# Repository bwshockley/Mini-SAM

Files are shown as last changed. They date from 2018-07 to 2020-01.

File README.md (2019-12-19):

# Mini SAM
Mini SAM is a LEGO® minifigure-sized development board based on either the Microchip SAMD51G 48-Pin 32-Bit ARM® Cortex®-M4F MCU (Mini SAM M4) or the Microchip SAMD21G 48-Pin 32-Bit ARM® Cortex®-M0+ MCU running at 48Mhz.

## Board Features

### I/O
The boards includes a usb-micro interface for programming and power.   Around the edge are 0.050" spaced holes with castellations outside of that and the plan is to have a "breakout" board with standard .100" headers.  There is an optional board design in work that will be 4-layer and have the .100" smt header pads included.

The Mini SAM boards include two LED indicators; a standard "Built-In" LED and an APA102 RGB LED.  There are two built-in buttons as well; a RESET button and a user programmable BUTTON.

### Memory
In order to support CircuitPython, a 2MB Quad-SPI flash memory chip is included.  This provides plenty of space for the CircuitPython program as well as space for user programming.

### Other
The boards include a 600mA 3.3V regulator, more than enough to power this little board and its built-in features.  The micro-USB circuitry includes optional provisioning for case grounding and ESD protection.  Finally, The AREF input and recommended Analog and Digital power separation is present on the board.

## BOM
Please see the BOM for each board

## Bootloader
A UF2 bootloader is available for the M4 board (will be available for the M0 when ready).  This bootloader may be built from source using my UF2 repository or downloaded from the [Minifigboards Software](https://www.minifigboards.com/mini-sam-m4/software/) page.

Source: [UF2-SAMDX1](https://github.com/bwshockley/uf2-samdx1) 

## Arduino
Arduino firmware is available for the M4 board as well. Instructions for adding the board to the board manager in the Arduino IDE are available on the [Minifigboards Software](https://www.minifigboards.com/mini-sam-m4/software/) page.

## CircuitPython
CircuitPython is available for the M4 board. [Mini SAM M4](https://circuitpython.org/board/mini_sam_m4/)  
CircuitPython will soon be available for the M0 board.

## Open Source
Boards can be ordered direct from [OSHPark](https://oshpark.com/profiles/bwshockley).

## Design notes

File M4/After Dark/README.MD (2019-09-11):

This is the repository for the "After Dark" version of the Mini SAM M4 board.  This design was talored for the "After Dark" option at oshpark.com, but should work for other PCB manufacturing that involves a clear solder mask.

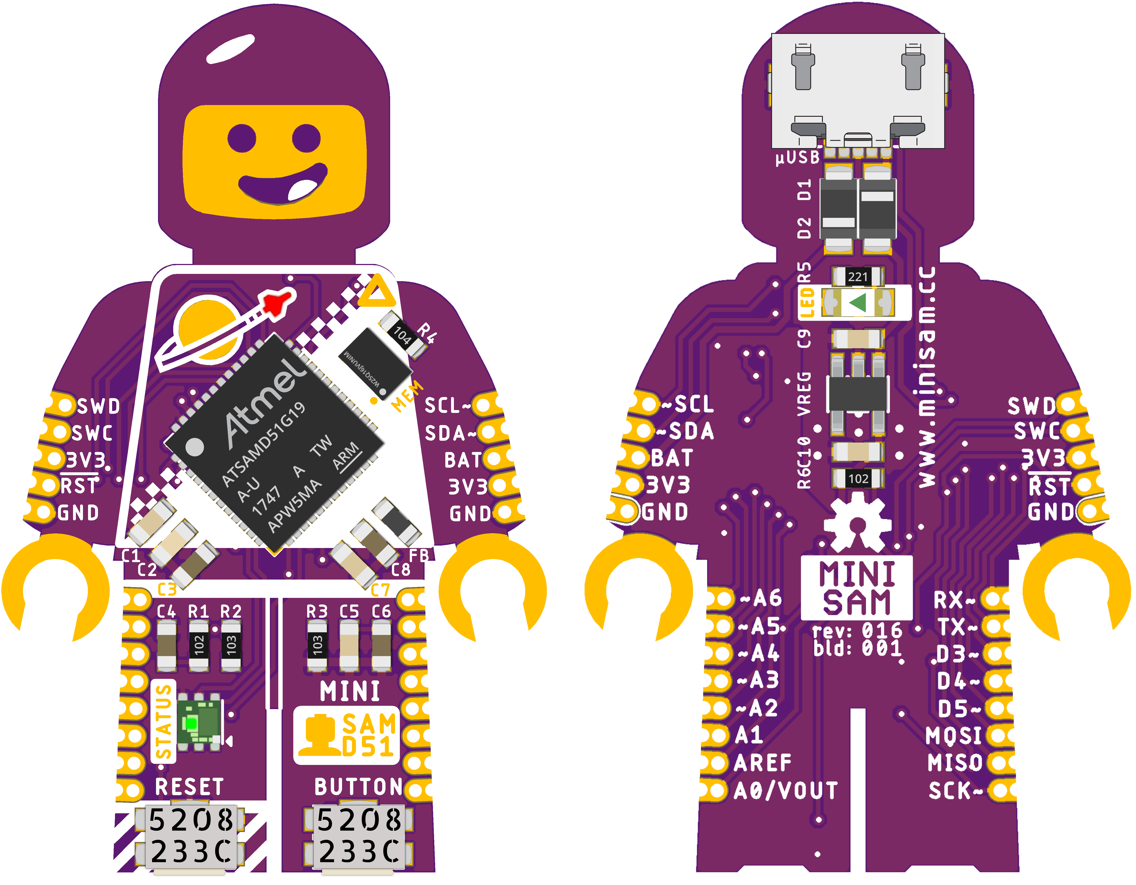
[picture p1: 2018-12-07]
docs/Complete.png

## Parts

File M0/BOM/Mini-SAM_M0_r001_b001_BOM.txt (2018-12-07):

Qty Value                                                            Device                Package                       Parts           Description                                 PROD_ID    VALUE
4   0.1µF                                                            CAP_CERAMIC_0603MP    _0603MP                       C3, C4, C6, C8  Ceramic Capacitors                                          
1   100kO                                                            RESISTOR_0603MP       _0603MP                       R4              Resistors                                                   
2   10KO                                                             RESISTOR_0603MP       _0603MP                       R2, R3          Resistors                                                   
4   10µF                                                             CAP_CERAMIC_0603MP    _0603MP                       C2, C7, C9, C10 Ceramic Capacitors                                          
2   1KO                                                              RESISTOR_0603MP       _0603MP                       R1, R6          Resistors                                                   
2   1X5_HEADER_1.27MMCAST                                            1X5_HEADER_1.27MMCAST 1X5_HEADER_1.27MM_CASTELLATED J2, J4                                                                      
2   1X8_HEADER_1.27MMCAST                                            1X8_HEADER_1.27MMCAST 1X8_HEADER_1.27MM_CASTELLATED J3, J5                                                                      
1   220O                                                             RESISTOR_0603MP       _0603MP                       R5              Resistors                                                   
2   4.7µF                                                            CAP_CERAMIC_0603MP    _0603MP                       C1, C5          Ceramic Capacitors                                          
1   AP102-2020                                                       APA1022020            APA102_2020                   RGB             APA102/DotStar Pixels                                       
1   AP2112K-3.3V                                                     V_REG_AP2112K-3.3V    SOT23-5                       VREG            AP2112 - 600mA CMOS LDO Regulator w/ Enable VREG-12457 3.3V 
1   ATSAMD21G18                                                      ATSAMD21G_QFN         TQFN48_7MM                    U1                                                                          
1   Easily mounted up-sdie down.                                     LED0805_NOOUTLINE     CHIPLED_0805_NOOUTLINE        LED             LED                                                         
1   Impedence: 50 ohm @ 20 MHz, 220 Ohm @ 100 MHz; low DC resistance FERRITE_0603MP        _0603MP                       FB              Ferrite Bead                                                
2   KMS233GLFG                                                       KMS_SWITCHKMS         KMS_SWITCH                    SW1, SW2                                                                    
2   MBR120                                                           DIODE_SOD-123FL       SOD-123FL                     D1, D2          Diode                                                       
1   MOLEX_47346-100147346                                            MOLEX_47346-100147346 MOLEX_47346-1001              J1                                                                          
1   flash                                                            SPIFLASH_8PINUX       USON8                         U3              SOIC8 SPI Flash

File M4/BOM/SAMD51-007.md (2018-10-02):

**Check the capacitors!  I've made a mistake and this BOM is wrong.  Will update when I can.**

Partlist exported from C:/Users/shockleyb/CloudStation/Eagle/Circuits/MiniSAMD51/Mini-SAM-D51/MINI_SAM_D51_007.sch at 7/31/2018 3:42 PM

Qty Value                 Device                Package                Parts               Description                                 
Others
1                         FERRITE BEAD*         0603                   FB                  Ferrite Bead
1                         LED                   0603                   L                   LED                                         
                            
Capacitors
5   0.1µF                 CAP_CERAMIC           0603                   C1, C3, C7, C8, C12 Ceramic Capacitors
4   10µF                  CAP_CERAMIC           0603                   C2, C9, C10, C11    Ceramic Capacitors
1   4.7nF                 CAP_CERAMIC           0603                   C13                 Ceramic Capacitors                          
1   4.7µF                 CAP_CERAMIC           0603                   C6                  Ceramic Capacitors

Resistors
1   100k                  RESISTOR              0603                   R7                  Resistors                                   
2   10K                   RESISTOR              0603                   R4, R5              Resistors                                   
1   1M                    RESISTOR              0603                   R6                  Resistors                                   
2   1k                    RESISTOR              0603                   R2**, R8            Resistors                                   
1   330Ohm                RESISTOR              0603                   R3                  Resistors                                   

ICs
1   AP102-2020            APA1022020            APA102_2020            RGB                 APA102/DotStar Pixels                       
1   AP2112K-3.3V          AP2112K-3.3V          SOT23-5                VREG                AP2112 - 600mA CMOS LDO Regulator w/ Enable 
1   ATSAMD51G_TQFN48      ATSAMD51G_TQFN48      TQFN48_7MM             IC4                 Main CPU    
1   2MB FLASH             IS25LP016D-JULE       USON8 (2x3mm)          U1                  USON8 2mmx3mm QSPI Flash
1   PRTR5V0U2X            PRTR5V0U2X            SOT143B                IC2                 ESD Protection for USB.

Connectors/Switches
2   KMS233GLFG            KMS_SWITCHKMS         KMS_SWITCH             SW1, SW2                                                        
1   MOLEX_47346-100147346 MOLEX_47346-100147346 MOLEX_47346-1001       J1                  Micro-USB Connector

Headers
1                         CORTEX_DEBUG_PTH      2X5-PTH-1.27MM         J2                  Cortex Debug Connector - 10 pin
2                         PINHD-1X111X11_SMT    1X11_SMT               J3, J4              PIN HEADER, SMT   

*The bead should provide enough impedance (e.g., 50Ω at 20 MHz and 220Ω at 100 MHz) to separate the digital and analog power domains.
Make sure to select a ferrite bead designed for filtering applications with a low DC resistance to avoid a large voltage drop across
the ferrite bead.

**R2 is the LED (L) resistor and when choosing your 0603 sized LED, please choose a resistor to match based on 3.3V supply voltage,
LED voltage drop and desired current.

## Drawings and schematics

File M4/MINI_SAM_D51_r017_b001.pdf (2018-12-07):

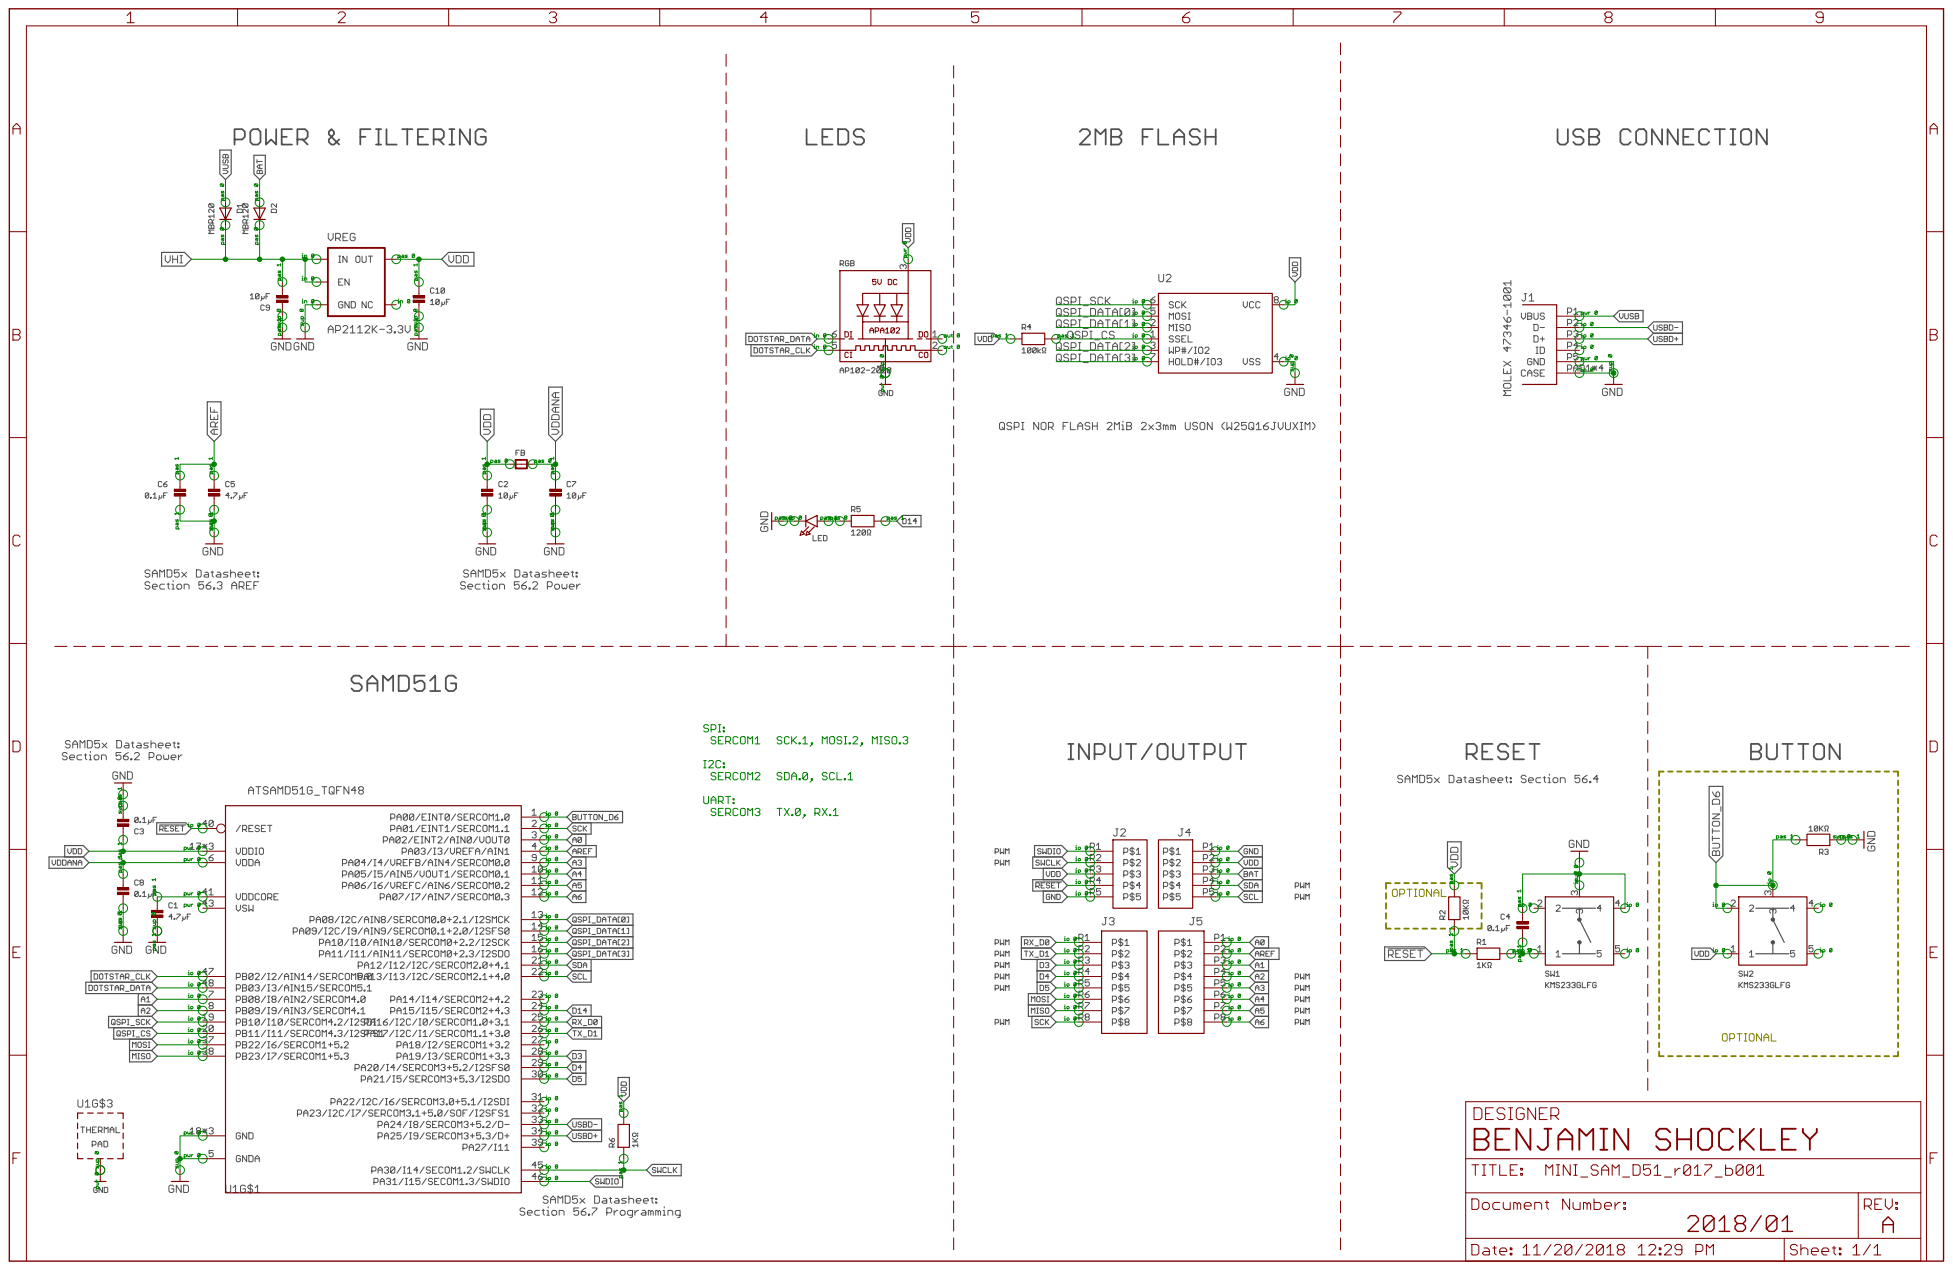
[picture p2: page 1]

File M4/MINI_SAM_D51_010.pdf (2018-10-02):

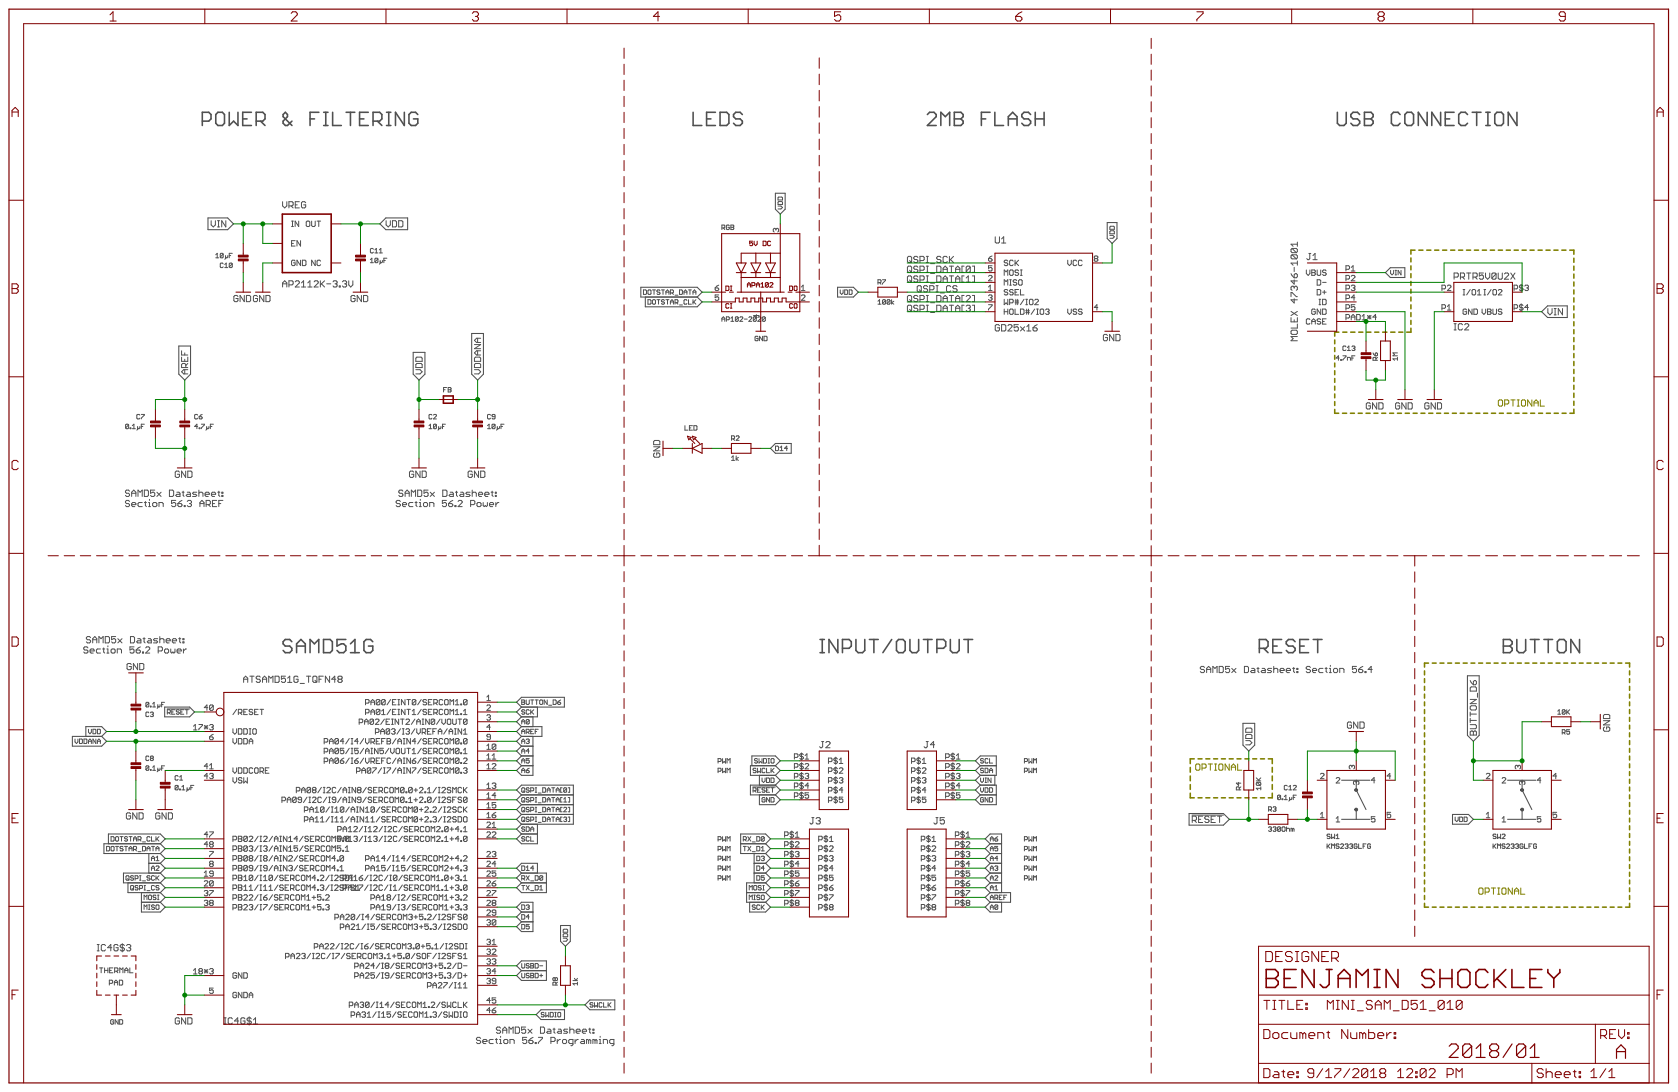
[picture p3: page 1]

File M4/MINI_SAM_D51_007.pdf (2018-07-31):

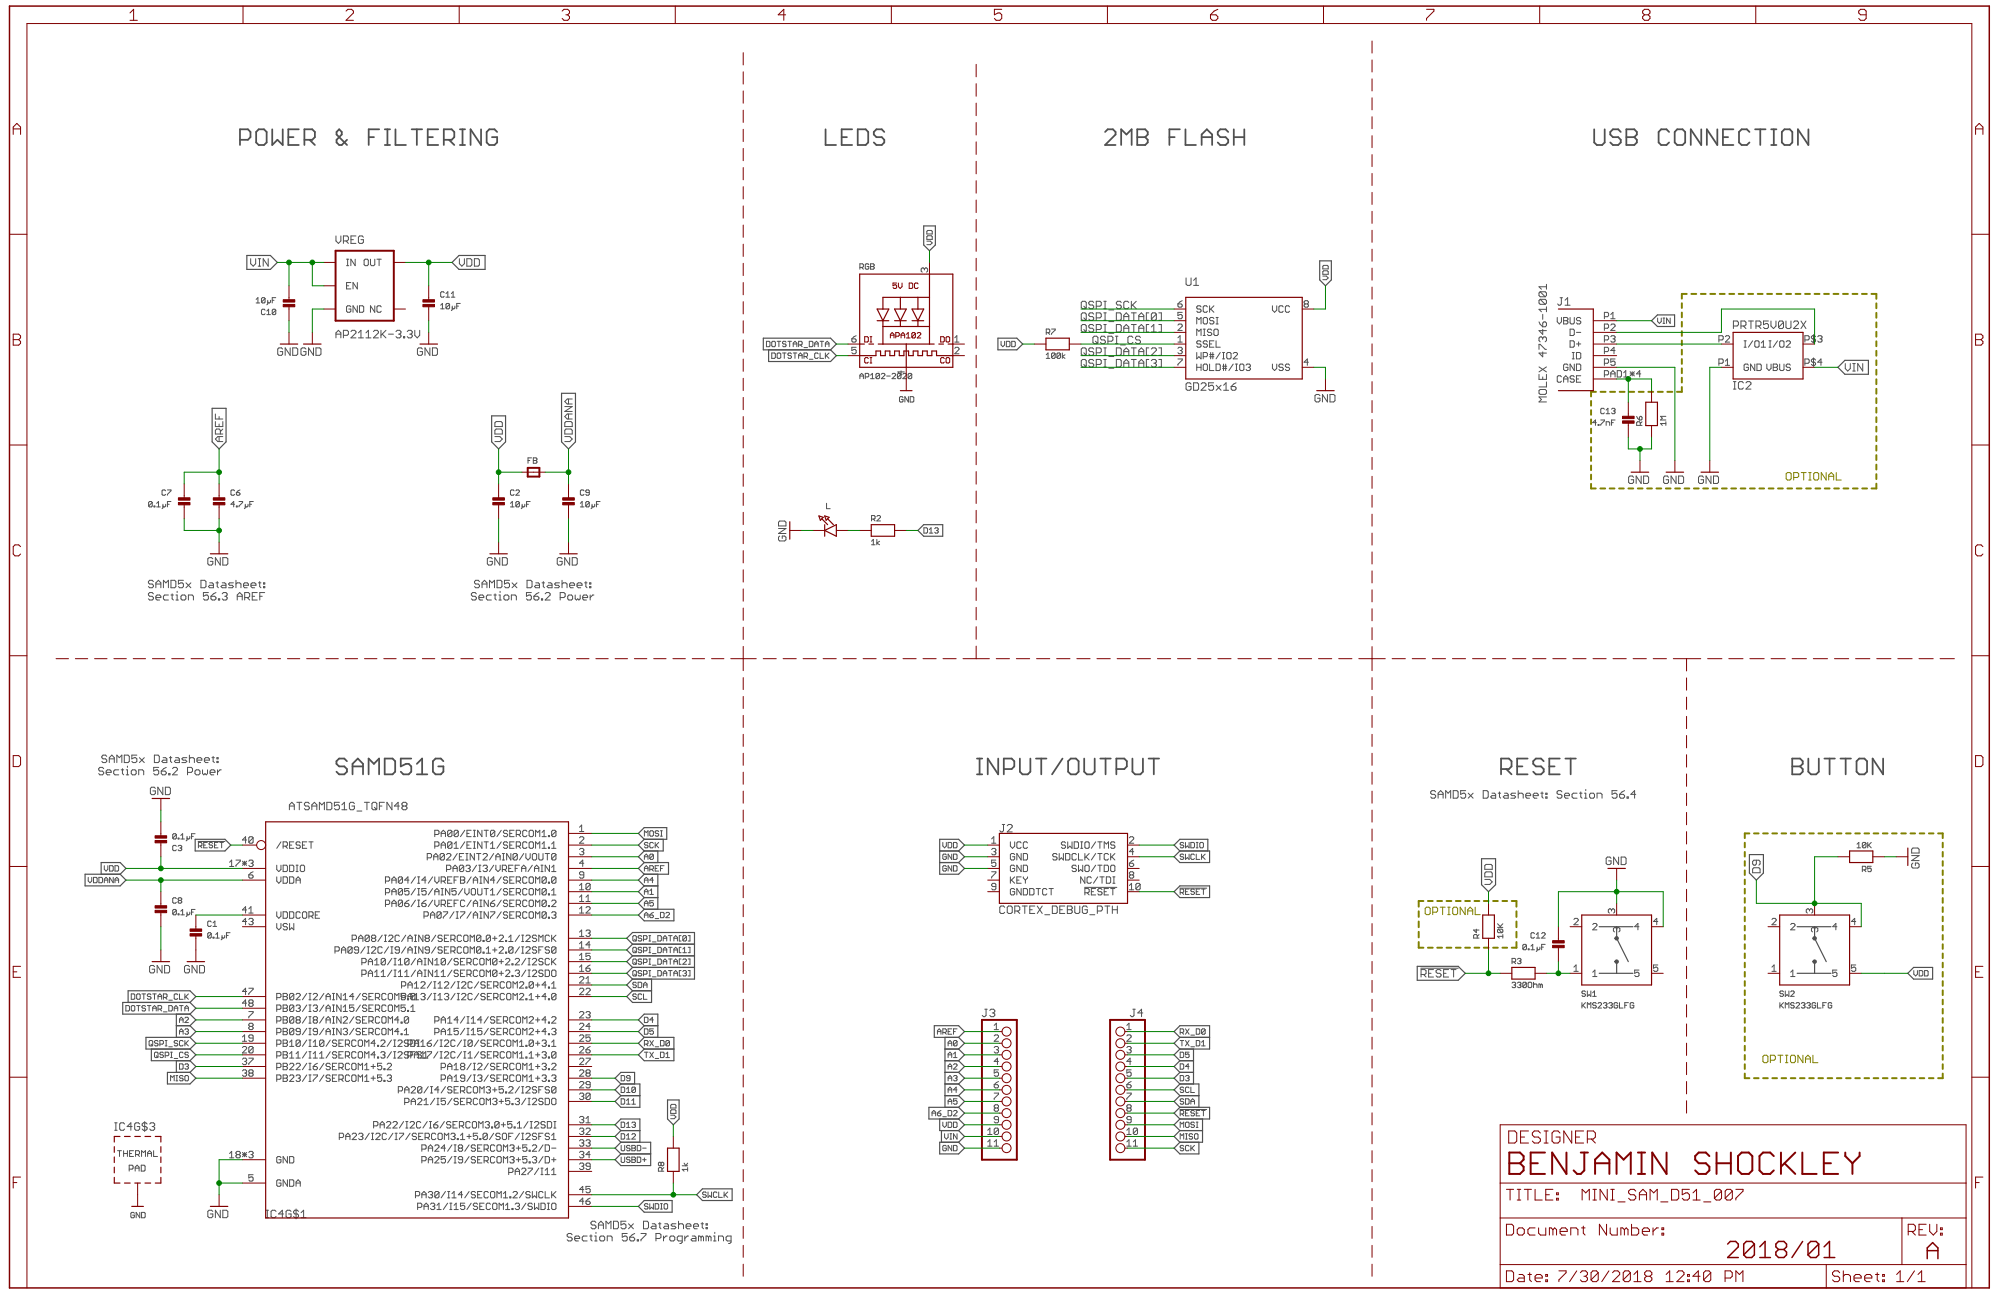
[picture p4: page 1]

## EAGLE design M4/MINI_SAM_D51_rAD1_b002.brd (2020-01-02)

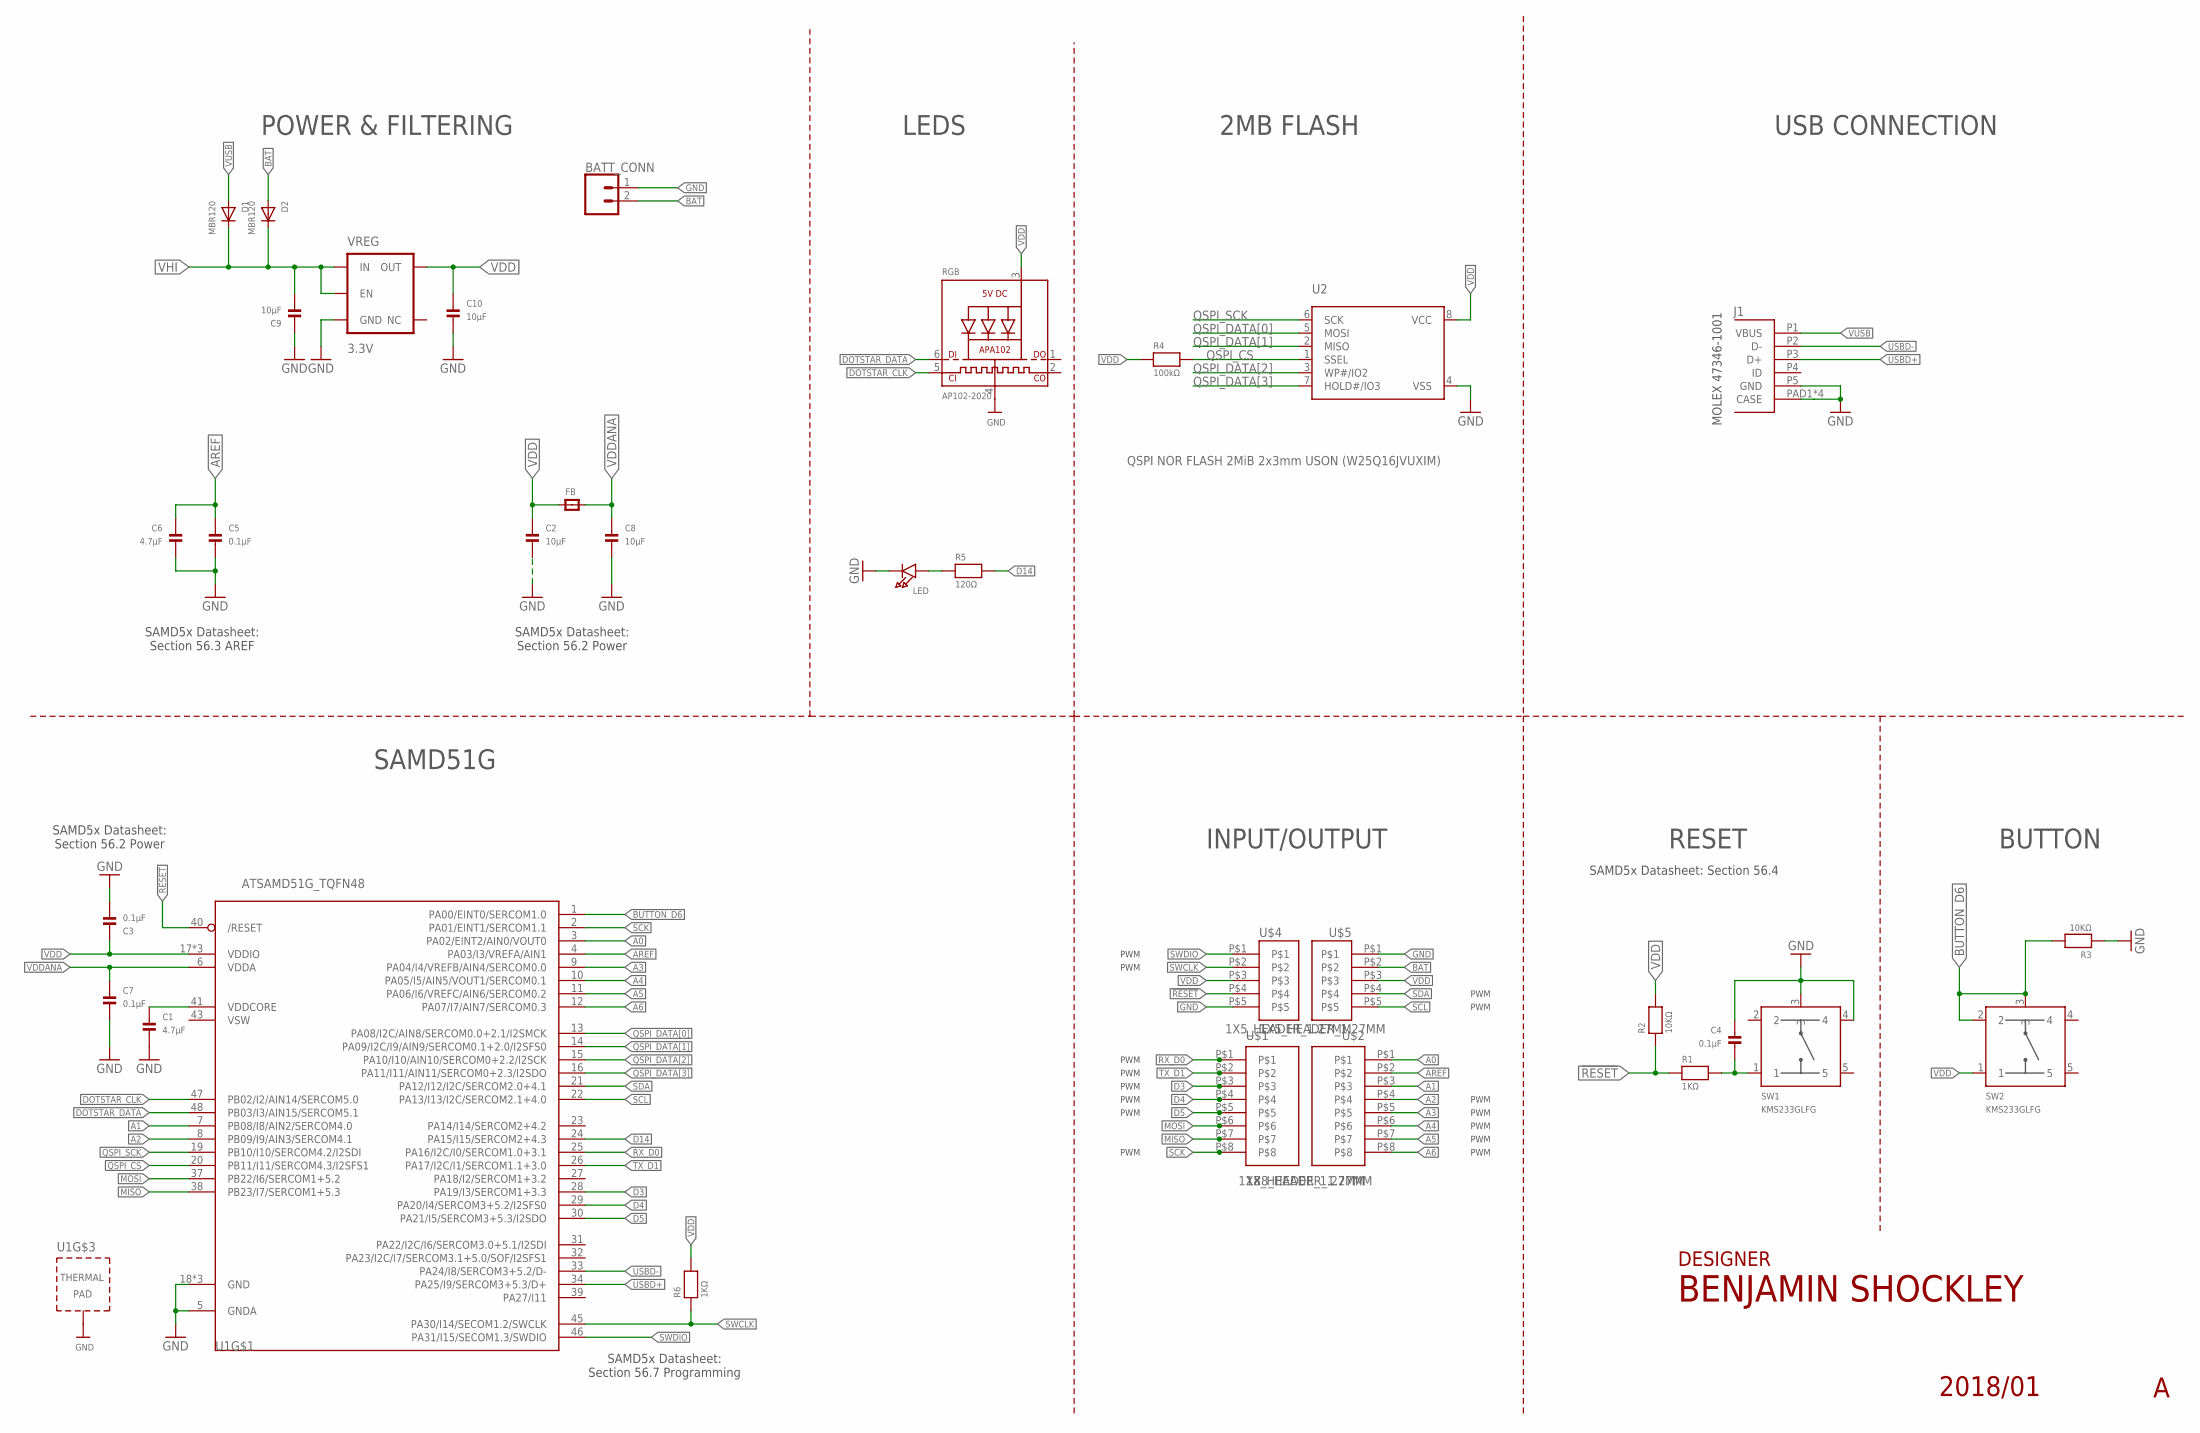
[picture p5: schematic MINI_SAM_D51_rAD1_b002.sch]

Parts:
BATT_CONN: CONN_02-JST-2MM-SMT; JST-2-SMD_NO_PASTE
C1, C6: 4.7µF; 0603_CAPACITOR
C2, C8, C9, C10: 10µF; 0603_CAPACITOR
C3, C4, C5, C7: 0.1µF; 0603_CAPACITOR
D1, D2: MBR120; SOD-123FL
FB: Impedence: 50 ohm @ 20 MHz, 220 Ohm @ 100 MHz; lo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; 0603_INDUCTOR
J1: MOLEX_47346-100147346; MOLEX_47346-1001
LED: VLRK31Q1R2-GS08; REVERSE_MOUNT_LED
R1, R6: 1KΩ; 0603_RESISTOR
R2, R3: 10KΩ; 0603_RESISTOR
R4: 100kΩ; 0603_RESISTOR
R5: 120Ω; 0603_RESISTOR
RGB: AP102-2020; APA102_2020
SW1, SW2: KMS233GLFG; KMS_SWITCH
U1: ATSAMD51G_TQFN48; TQFN48_7MM
U2: QSPI NOR FLASH 2MiB 2x3mm USON (W25Q16JVUXIM); USON8
U$1, U$2: 1X8_HEADER_1.27MM
U$4, U$5: 1X5_HEADER_1.27MM
VREG: 3.3V; SOT23-5

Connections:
!RESET: R1.1, R2.1, U1.40 (/RESET), U$4.P$4
A0: U1.3 (PA02/EINT2/AIN0/VOUT0), U$2.P$1
A1: U1.7 (PB08/I8/AIN2/SERCOM4.0), U$2.P$3
A2: U1.8 (PB09/I9/AIN3/SERCOM4.1), U$2.P$4
A3: U1.9 (PA04/I4/VREFB/AIN4/SERCOM0.0), U$2.P$5
A4: U1.10 (PA05/I5/AIN5/VOUT1/SERCOM0.1), U$2.P$6
A5: U1.11 (PA06/I6/VREFC/AIN6/SERCOM0.2), U$2.P$7
A6: U1.12 (PA07/I7/AIN7/SERCOM0.3), U$2.P$8
AREF: C5.1, C6.1, U1.4 (PA03/I3/VREFA/AIN1), U$2.P$2
BAT: BATT_CONN.2 (1), D2.A, U$5.P$2
BUTTON_D6: R3.2, SW2.2, SW2.3, U1.1 (PA00/EINT0/SERCOM1.0)
D3: U1.28 (PA19/I3/SERCOM1+3.3), U$1.P$3
D4: U1.29 (PA20/I4/SERCOM3+5.2/I2SFS0), U$1.P$4
D5: U1.30 (PA21/I5/SERCOM3+5.3/I2SDO), U$1.P$5
D14: R5.2, U1.24 (PA15/I15/SERCOM2+4.3)
DOTSTAR_CLK: RGB.5 (CKI), U1.47 (PB02/I2/AIN14/SERCOM5.0)
DOTSTAR_DATA: RGB.6 (DI), U1.48 (PB03/I3/AIN15/SERCOM5.1)
GND: BATT_CONN.1 (2), C1.2, C2.2, C3.2, C4.1, C5.2, C6.2, C7.2, C8.2, C9.1, C10.2, J1.P5 (GND), J1.PAD1 (CASE), J1.PAD2 (CASE), J1.PAD3 (CASE), J1.PAD4 (CASE), LED.C, R3.1, RGB.4 (GND), SW1.3, SW1.4, U1.5 (GNDA), U1.18 (GND), U1.35 (GND), U1.42 (GND), U1.THERMAL (TP), U2.4 (VSS), U$4.P$5, U$5.P$1, VREG.2 (GND)
MISO: U1.38 (PB23/I7/SERCOM1+5.3), U$1.P$7
MOSI: U1.37 (PB22/I6/SERCOM1+5.2), U$1.P$6
unnamed: LED.A, R5.1
unnamed: C4.2, R1.2, SW1.1
unnamed: C1.1, U1.41 (VDDCORE)
QSPI_CS: R4.2, U1.20 (PB11/I11/SERCOM4.3/I2SFS1), U2.1 (SSEL)
QSPI_DATA[0]: U1.13 (PA08/I2C/AIN8/SERCOM0.0+2.1/I2SMCK), U2.5 (MOSI)
QSPI_DATA[1]: U1.14 (PA09/I2C/I9/AIN9/SERCOM0.1+2.0/I2SFS0), U2.2 (MISO)
QSPI_DATA[2]: U1.15 (PA10/I10/AIN10/SERCOM0+2.2/I2SCK), U2.3 (WP#/IO2)
QSPI_DATA[3]: U1.16 (PA11/I11/AIN11/SERCOM0+2.3/I2SDO), U2.7 (HOLD#/IO3)
QSPI_SCK: U1.19 (PB10/I10/SERCOM4.2/I2SDI), U2.6 (SCK)
RX_D0: U1.25 (PA16/I2C/I0/SERCOM1.0+3.1), U$1.P$1
SCK: U1.2 (PA01/EINT1/SERCOM1.1), U$1.P$8
SCL: U1.22 (PA13/I13/I2C/SERCOM2.1+4.0), U$5.P$5
SDA: U1.21 (PA12/I12/I2C/SERCOM2.0+4.1), U$5.P$4
SWCLK: R6.1, U1.45 (PA30/I14/SECOM1.2/SWCLK), U$4.P$2
SWDIO: U1.46 (PA31/I15/SECOM1.3/SWDIO), U$4.P$1
TX_D1: U1.26 (PA17/I2C/I1/SERCOM1.1+3.0), U$1.P$2
USBD+: J1.P3 (D+), U1.34 (PA25/I9/SERCOM3+5.3/D+)
USBD-: J1.P2 (D-), U1.33 (PA24/I8/SERCOM3+5.2/D-)
VDD: C2.1, C3.1, C10.1, FB.1, R2.2, R4.1, R6.2, RGB.3 (VDD), SW2.1, U1.17 (VDDIO), U1.36 (VDDIO), U1.44 (VDDIO), U2.8 (VCC), U$4.P$3, U$5.P$3, VREG.5 (OUT)
VDDANA: C7.1, C8.1, FB.2, U1.6 (VDDA)
VHI: C9.2, D1.C, D2.C, VREG.1 (IN), VREG.3 (EN)
VSW: U1.43 (VSW)
VUSB: D1.A, J1.P1 (VBUS)

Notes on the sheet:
INPUT/OUTPUT
RESET
POWER & FILTERING
SAMD51G
LEDS
USB CONNECTION
MOLEX 47346-1001
BUTTON
DESIGNER
SAMD5x Datasheet: Section 56.4
2MB FLASH
SAMD5x Datasheet: Section 56.3 AREF
SAMD5x Datasheet: Section 56.2 Power
SAMD5x Datasheet: Section 56.7 Programming
PWM

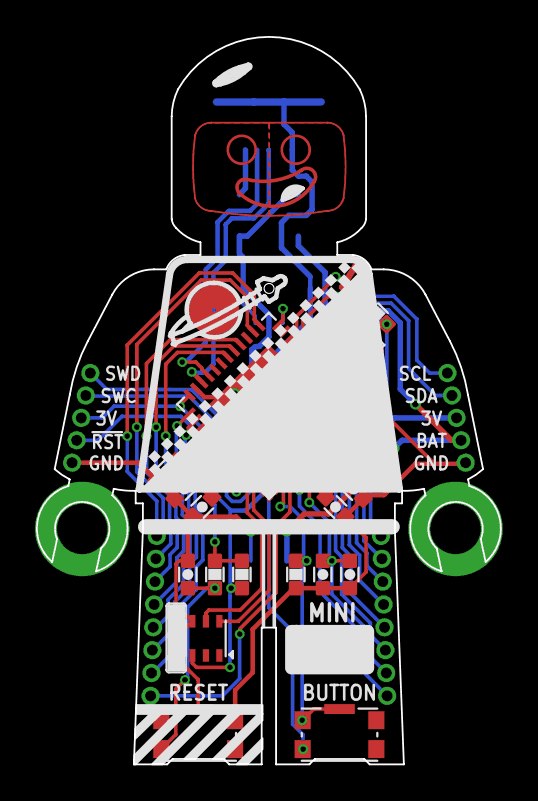
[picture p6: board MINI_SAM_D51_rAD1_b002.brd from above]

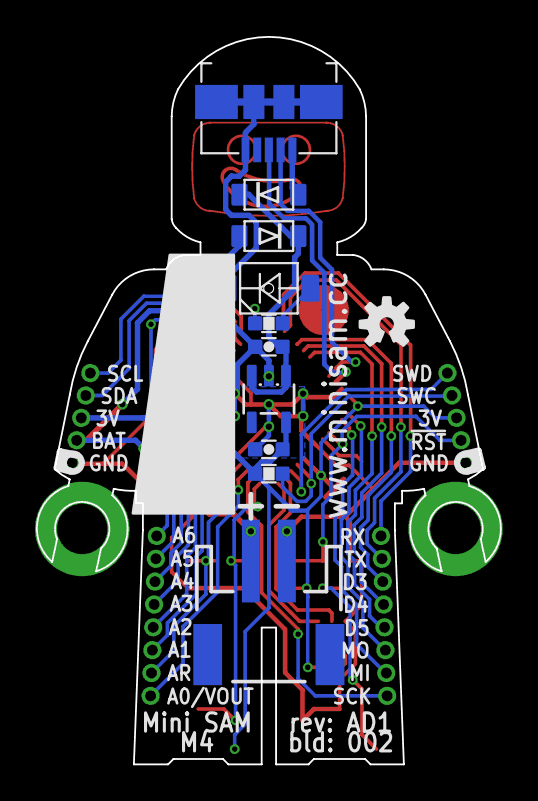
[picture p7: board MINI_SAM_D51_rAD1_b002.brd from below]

Board: 2 copper layers, 25.8 x 40.4 mm, 33 parts (11 on the bottom side), 42 nets.

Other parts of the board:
U$3: OSHW-LOGO-S

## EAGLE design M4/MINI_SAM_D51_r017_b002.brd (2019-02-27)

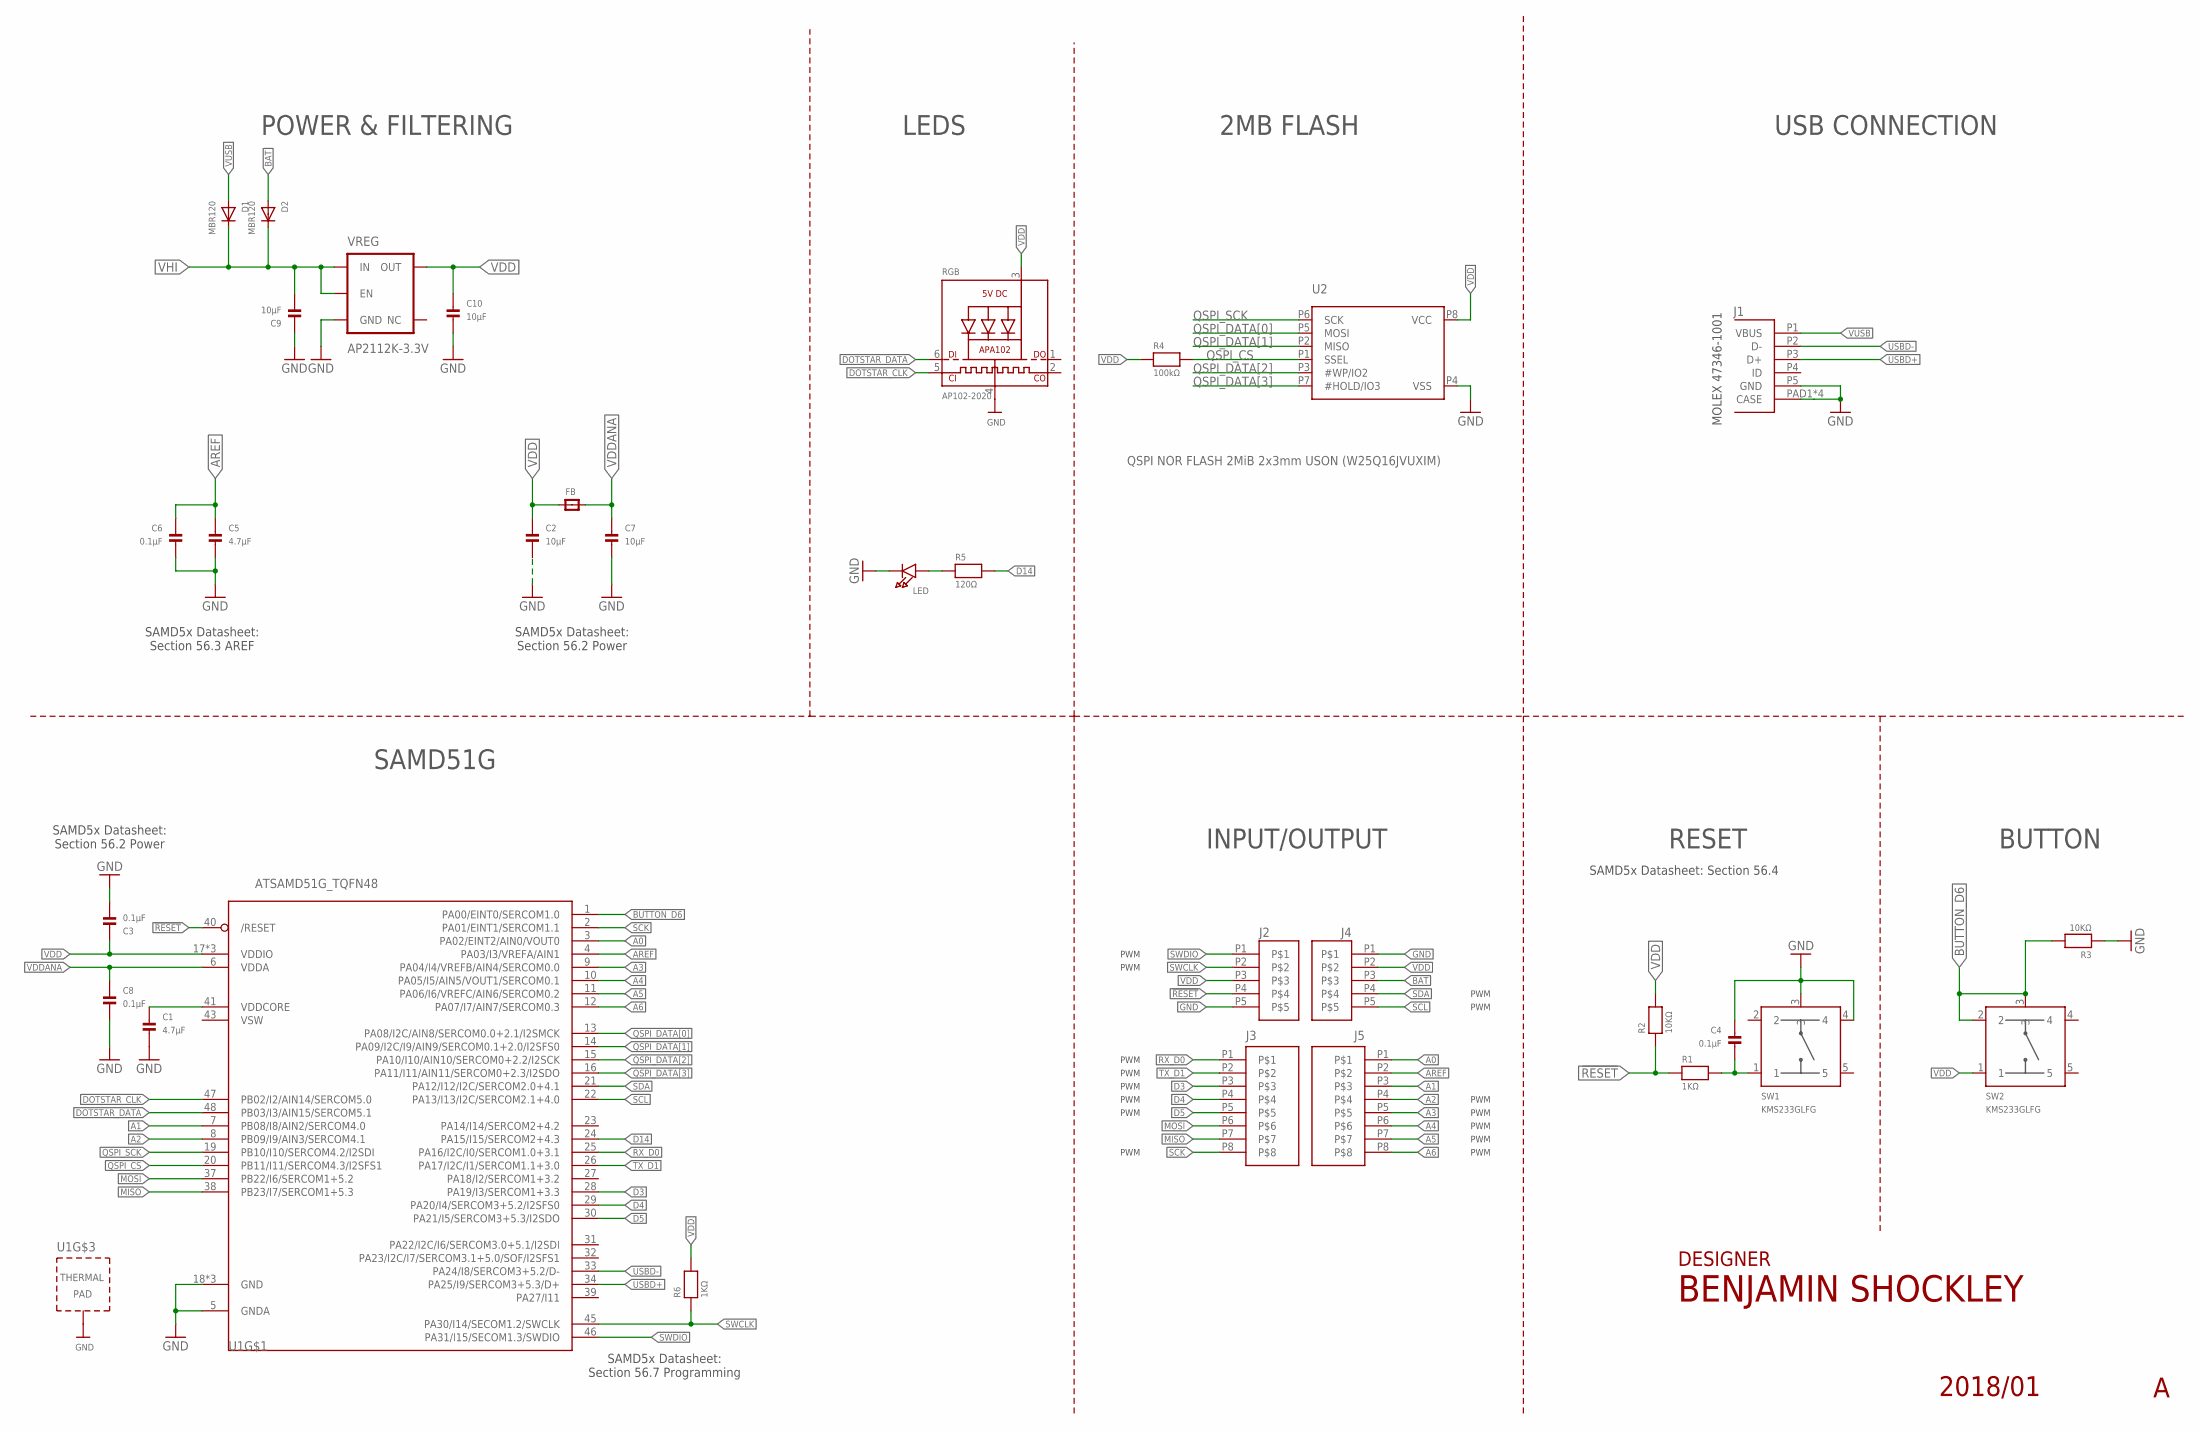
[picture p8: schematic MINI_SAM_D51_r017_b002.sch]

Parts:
C1, C5: 4.7µF; _0603MP
C2, C7, C9, C10: 10µF; _0603MP
C3, C4, C6, C8: 0.1µF; _0603MP
D1, D2: MBR120; SOD-123FL
FB: Impedence: 50 ohm @ 20 MHz, 220 Ohm @ 100 MHz; lo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; _0603MP
J1: MOLEX_47346-100147346; MOLEX_47346-1001
J2, J4: 1X5_HEADER_1.27MMCAST; 1X5_HEADER_1.27MM_CASTELLATED
J3, J5: 1X8_HEADER_1.27MMCAST; 1X8_HEADER_1.27MM_CASTELLATED
LED: VLRK31Q1R2-GS08; REVERSE_MOUNT_LED
R1, R6: 1KΩ; _0603MP
R2, R3: 10KΩ; _0603MP
R4: 100kΩ; _0603MP
R5: 120Ω; _0603MP
RGB: AP102-2020; APA102_2020
SW1, SW2: KMS233GLFG; KMS_SWITCH
U1: ATSAMD51G_TQFN48; TQFN48_7MM
U2: QSPI NOR FLASH 2MiB 2x3mm USON (W25Q16JVUXIM); USON4X3
VREG: AP2112K-3.3V; SOT23-5

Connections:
!RESET: J2.P4, R1.1, R2.1, U1.40 (/RESET)
A0: J5.P1, U1.3 (PA02/EINT2/AIN0/VOUT0)
A1: J5.P3, U1.7 (PB08/I8/AIN2/SERCOM4.0)
A2: J5.P4, U1.8 (PB09/I9/AIN3/SERCOM4.1)
A3: J5.P5, U1.9 (PA04/I4/VREFB/AIN4/SERCOM0.0)
A4: J5.P6, U1.10 (PA05/I5/AIN5/VOUT1/SERCOM0.1)
A5: J5.P7, U1.11 (PA06/I6/VREFC/AIN6/SERCOM0.2)
A6: J5.P8, U1.12 (PA07/I7/AIN7/SERCOM0.3)
AREF: C5.1, C6.1, J5.P2, U1.4 (PA03/I3/VREFA/AIN1)
BAT: D2.A, J4.P3
BUTTON_D6: R3.2, SW2.2, SW2.3, U1.1 (PA00/EINT0/SERCOM1.0)
D3: J3.P3, U1.28 (PA19/I3/SERCOM1+3.3)
D4: J3.P4, U1.29 (PA20/I4/SERCOM3+5.2/I2SFS0)
D5: J3.P5, U1.30 (PA21/I5/SERCOM3+5.3/I2SDO)
D14: R5.2, U1.24 (PA15/I15/SERCOM2+4.3)
DOTSTAR_CLK: RGB.5 (CKI), U1.47 (PB02/I2/AIN14/SERCOM5.0)
DOTSTAR_DATA: RGB.6 (DI), U1.48 (PB03/I3/AIN15/SERCOM5.1)
GND: C1.2, C2.2, C3.2, C4.1, C5.2, C6.2, C7.2, C8.2, C9.1, C10.2, J1.P5 (GND), J1.PAD1 (CASE), J1.PAD2 (CASE), J1.PAD3 (CASE), J1.PAD4 (CASE), J2.P5, J4.P1, LED.C, R3.1, RGB.4 (GND), SW1.3, SW1.4, U1.5 (GNDA), U1.18 (GND), U1.35 (GND), U1.42 (GND), U1.THERMAL (TP), U2.P4 (VSS), VREG.2 (GND)
MISO: J3.P7, U1.38 (PB23/I7/SERCOM1+5.3)
MOSI: J3.P6, U1.37 (PB22/I6/SERCOM1+5.2)
unnamed: LED.A, R5.1
unnamed: C4.2, R1.2, SW1.1
unnamed: C1.1, U1.41 (VDDCORE)
QSPI_CS: R4.2, U1.20 (PB11/I11/SERCOM4.3/I2SFS1), U2.P1 (SSEL)
QSPI_DATA[0]: U1.13 (PA08/I2C/AIN8/SERCOM0.0+2.1/I2SMCK), U2.P5 (MOSI)
QSPI_DATA[1]: U1.14 (PA09/I2C/I9/AIN9/SERCOM0.1+2.0/I2SFS0), U2.P2 (MISO)
QSPI_DATA[2]: U1.15 (PA10/I10/AIN10/SERCOM0+2.2/I2SCK), U2.P3 (#WP/IO2)
QSPI_DATA[3]: U1.16 (PA11/I11/AIN11/SERCOM0+2.3/I2SDO), U2.P7 (#HOLD/IO3)
QSPI_SCK: U1.19 (PB10/I10/SERCOM4.2/I2SDI), U2.P6 (SCK)
RX_D0: J3.P1, U1.25 (PA16/I2C/I0/SERCOM1.0+3.1)
SCK: J3.P8, U1.2 (PA01/EINT1/SERCOM1.1)
SCL: J4.P5, U1.22 (PA13/I13/I2C/SERCOM2.1+4.0)
SDA: J4.P4, U1.21 (PA12/I12/I2C/SERCOM2.0+4.1)
SWCLK: J2.P2, R6.1, U1.45 (PA30/I14/SECOM1.2/SWCLK)
SWDIO: J2.P1, U1.46 (PA31/I15/SECOM1.3/SWDIO)
TX_D1: J3.P2, U1.26 (PA17/I2C/I1/SERCOM1.1+3.0)
USBD+: J1.P3 (D+), U1.34 (PA25/I9/SERCOM3+5.3/D+)
USBD-: J1.P2 (D-), U1.33 (PA24/I8/SERCOM3+5.2/D-)
VDD: C2.1, C3.1, C10.1, FB.1, J2.P3, J4.P2, R2.2, R4.1, R6.2, RGB.3 (VDD), SW2.1, U1.17 (VDDIO), U1.36 (VDDIO), U1.44 (VDDIO), U2.P8 (VCC), VREG.5 (OUT)
VDDANA: C7.1, C8.1, FB.2, U1.6 (VDDA)
VHI: C9.2, D1.C, D2.C, VREG.1 (IN), VREG.3 (EN)
VSW: U1.43 (VSW)
VUSB: D1.A, J1.P1 (VBUS)

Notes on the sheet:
INPUT/OUTPUT
RESET
POWER & FILTERING
SAMD51G
LEDS
USB CONNECTION
MOLEX 47346-1001
BUTTON
DESIGNER
SAMD5x Datasheet: Section 56.4
2MB FLASH
SAMD5x Datasheet: Section 56.3 AREF
SAMD5x Datasheet: Section 56.2 Power
SAMD5x Datasheet: Section 56.7 Programming
PWM

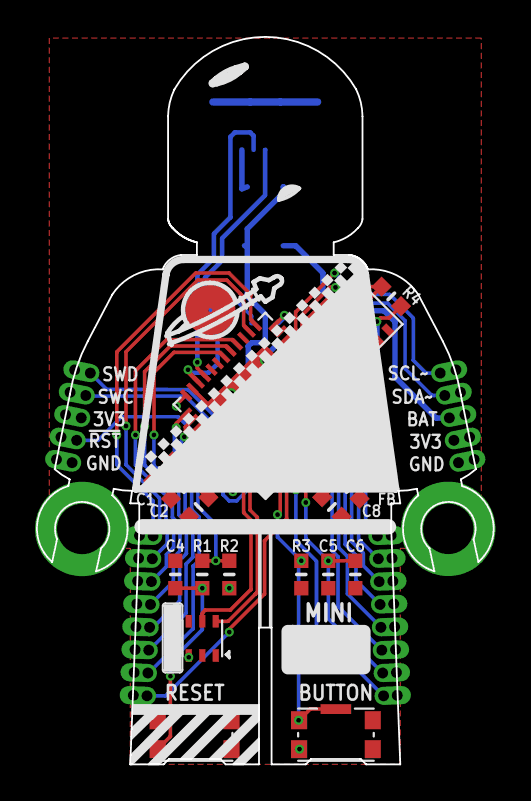
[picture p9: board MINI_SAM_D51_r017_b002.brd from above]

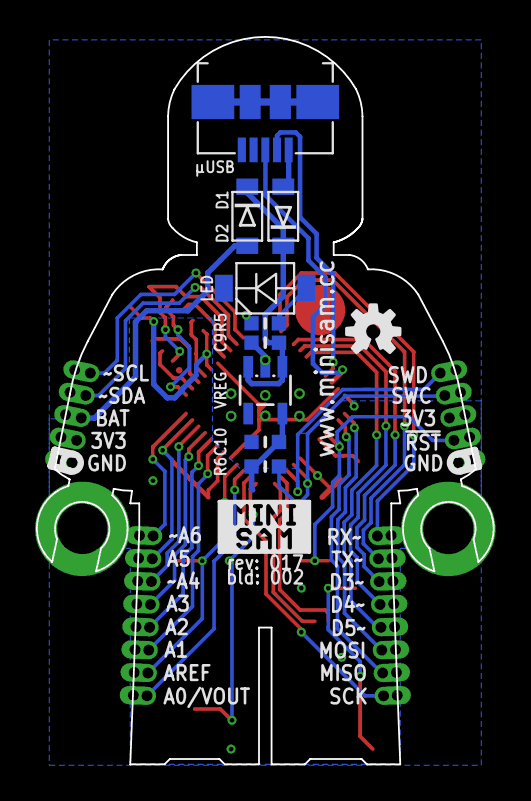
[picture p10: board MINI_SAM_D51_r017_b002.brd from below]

Board: 2 copper layers, 25.4 x 40.4 mm, 32 parts (10 on the bottom side), 42 nets.

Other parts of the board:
U$3: OSHW-LOGO-S

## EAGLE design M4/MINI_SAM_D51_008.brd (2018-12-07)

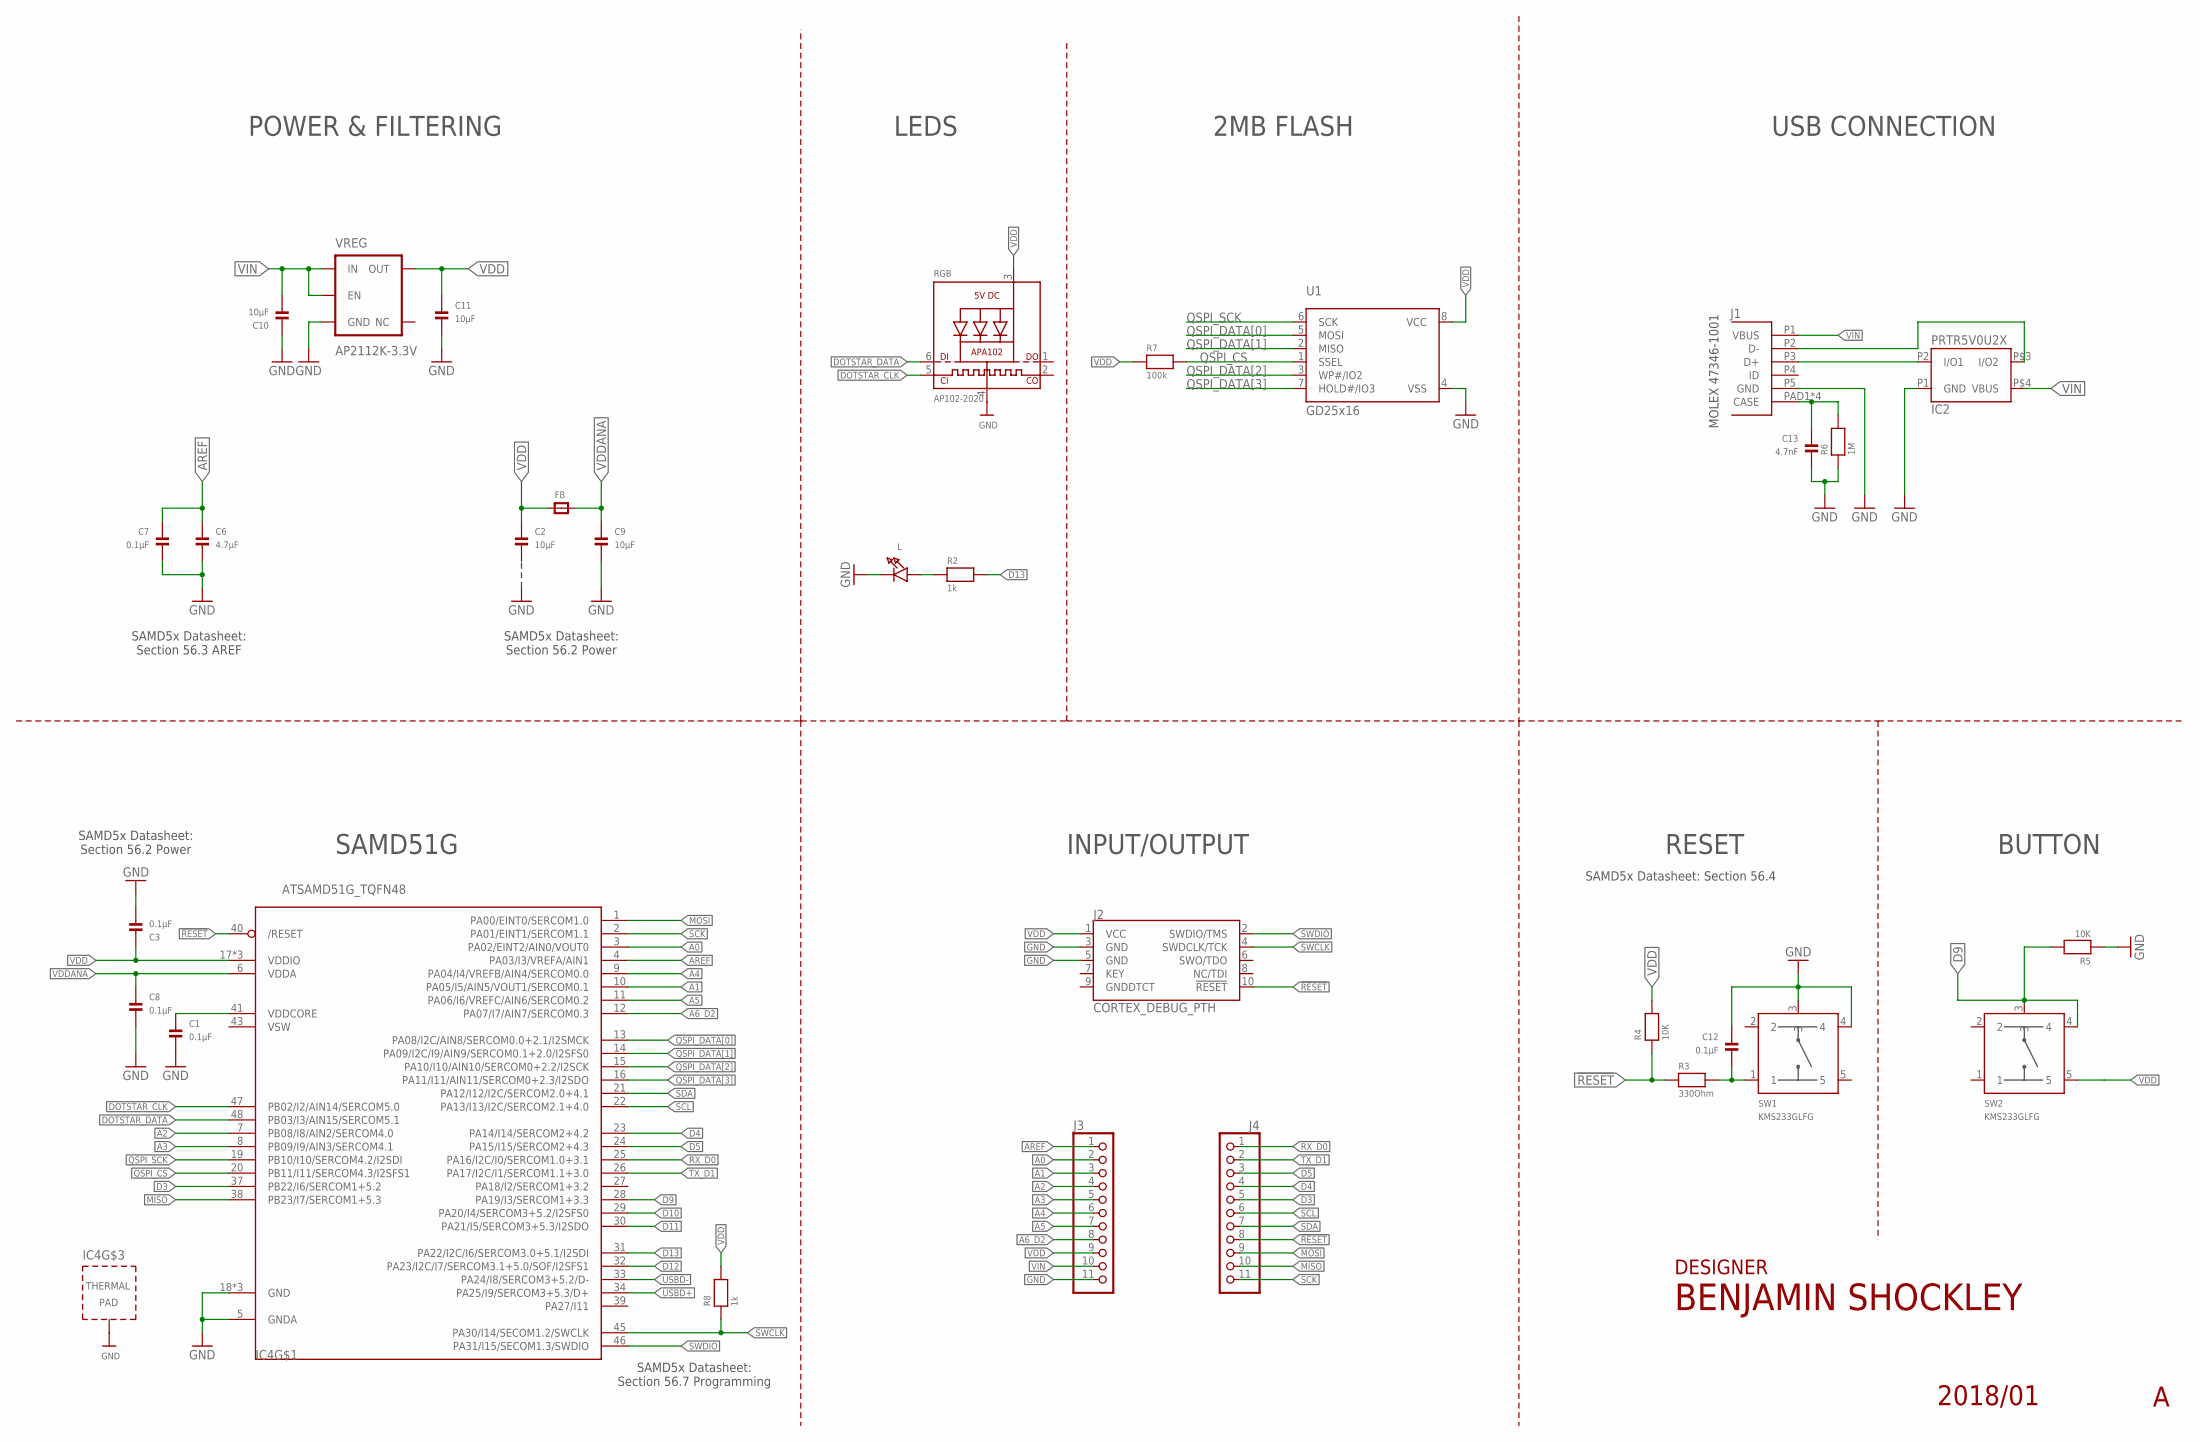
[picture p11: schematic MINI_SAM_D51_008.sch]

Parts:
C1, C3, C7, C8, C12: 0.1µF; _0603MP
C2, C9, C10, C11: 10µF; _0603MP
C6: 4.7µF; _0603MP
C13: 4.7nF; _0603MP
FB: FERRITE_0603MP; _0603MP
IC2: PRTR5V0U2X; SOT143B_REFLOW
IC4: ATSAMD51G_TQFN48; TQFN48_7MM
J1: MOLEX_47346-100147346; MOLEX_47346-1001
J2: CORTEX_DEBUG_PTH; 2X5-PTH-1.27MM
J3, J4: PINHD-1X111X11_SMT; 1X11_SMT
L: LED0603_NOOUTLINE; CHIPLED_0603_NOOUTLINE
R2, R8: 1k; _0603MP
R3: 330Ohm; _0603MP
R4, R5: 10K; _0603MP
R6: 1M; _0603MP
R7: 100k; _0603MP
RGB: AP102-2020; APA102_2020
SW1, SW2: KMS233GLFG; KMS_SWITCH
U1: GD25x16; USON8
VREG: AP2112K-3.3V; SOT23-5

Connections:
!RESET: IC4.40 (/RESET), J2.10 (!RESET), J4.8, R3.1, R4.1
A0: IC4.3 (PA02/EINT2/AIN0/VOUT0), J3.2
A1: IC4.10 (PA05/I5/AIN5/VOUT1/SERCOM0.1), J3.3
A2: IC4.7 (PB08/I8/AIN2/SERCOM4.0), J3.4
A3: IC4.8 (PB09/I9/AIN3/SERCOM4.1), J3.5
A4: IC4.9 (PA04/I4/VREFB/AIN4/SERCOM0.0), J3.6
A5: IC4.11 (PA06/I6/VREFC/AIN6/SERCOM0.2), J3.7
A6_D2: IC4.12 (PA07/I7/AIN7/SERCOM0.3), J3.8
AREF: C6.1, C7.1, IC4.4 (PA03/I3/VREFA/AIN1), J3.1
D3: IC4.37 (PB22/I6/SERCOM1+5.2), J4.5
D4: IC4.23 (PA14/I14/SERCOM2+4.2), J4.4
D5: IC4.24 (PA15/I15/SERCOM2+4.3), J4.3
D9: IC4.28 (PA19/I3/SERCOM1+3.3), R5.2, SW2.3, SW2.4
D10: IC4.29 (PA20/I4/SERCOM3+5.2/I2SFS0)
D11: IC4.30 (PA21/I5/SERCOM3+5.3/I2SDO)
D12: IC4.32 (PA23/I2C/I7/SERCOM3.1+5.0/SOF/I2SFS1)
D13: IC4.31 (PA22/I2C/I6/SERCOM3.0+5.1/I2SDI), R2.2
DOTSTAR_CLK: IC4.47 (PB02/I2/AIN14/SERCOM5.0), RGB.5 (CKI)
DOTSTAR_DATA: IC4.48 (PB03/I3/AIN15/SERCOM5.1), RGB.6 (DI)
GND: C1.2, C2.2, C3.2, C6.2, C7.2, C8.2, C9.2, C10.1, C11.2, C12.1, C13.2, IC2.P1 (GND), IC4.5 (GNDA), IC4.18 (GND), IC4.35 (GND), IC4.42 (GND), IC4.THERMAL (TP), J1.P5 (GND), J2.3 (GND), J2.5 (GND), J3.11, L.C, R5.1, R6.1, RGB.4 (GND), SW1.3, SW1.4, U1.4 (VSS), VREG.2 (GND)
MISO: IC4.38 (PB23/I7/SERCOM1+5.3), J4.10
MOSI: IC4.1 (PA00/EINT0/SERCOM1.0), J4.9
unnamed: C13.1, J1.PAD1 (CASE), J1.PAD2 (CASE), J1.PAD3 (CASE), J1.PAD4 (CASE), R6.2
unnamed: L.A, R2.1
unnamed: C12.2, R3.2, SW1.1
unnamed: C1.1, IC4.41 (VDDCORE)
QSPI_CS: IC4.20 (PB11/I11/SERCOM4.3/I2SFS1), R7.2, U1.1 (SSEL)
QSPI_DATA[0]: IC4.13 (PA08/I2C/AIN8/SERCOM0.0+2.1/I2SMCK), U1.5 (MOSI)
QSPI_DATA[1]: IC4.14 (PA09/I2C/I9/AIN9/SERCOM0.1+2.0/I2SFS0), U1.2 (MISO)
QSPI_DATA[2]: IC4.15 (PA10/I10/AIN10/SERCOM0+2.2/I2SCK), U1.3 (WP#/IO2)
QSPI_DATA[3]: IC4.16 (PA11/I11/AIN11/SERCOM0+2.3/I2SDO), U1.7 (HOLD#/IO3)
QSPI_SCK: IC4.19 (PB10/I10/SERCOM4.2/I2SDI), U1.6 (SCK)
RX_D0: IC4.25 (PA16/I2C/I0/SERCOM1.0+3.1), J4.1
SCK: IC4.2 (PA01/EINT1/SERCOM1.1), J4.11
SCL: IC4.22 (PA13/I13/I2C/SERCOM2.1+4.0), J4.6
SDA: IC4.21 (PA12/I12/I2C/SERCOM2.0+4.1), J4.7
SWCLK: IC4.45 (PA30/I14/SECOM1.2/SWCLK), J2.4 (SWDCLK/TCK), R8.1
SWDIO: IC4.46 (PA31/I15/SECOM1.3/SWDIO), J2.2 (SWDIO/TMS)
TX_D1: IC4.26 (PA17/I2C/I1/SERCOM1.1+3.0), J4.2
USBD+: IC2.P2 (I/O1), IC4.34 (PA25/I9/SERCOM3+5.3/D+), J1.P3 (D+)
USBD-: IC2.P$3 (I/O2), IC4.33 (PA24/I8/SERCOM3+5.2/D-), J1.P2 (D-)
VDD: C2.1, C3.1, C11.1, FB.1, IC4.17 (VDDIO), IC4.36 (VDDIO), IC4.44 (VDDIO), J2.1 (VCC), J3.9, R4.2, R7.1, R8.2, RGB.3 (VDD), SW2.5, U1.8 (VCC), VREG.5 (OUT)
VDDANA: C8.1, C9.1, FB.2, IC4.6 (VDDA)
VIN: C10.2, IC2.P$4 (VBUS), J1.P1 (VBUS), J3.10, VREG.1 (IN), VREG.3 (EN)
VSW: IC4.43 (VSW)

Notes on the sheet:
INPUT/OUTPUT
RESET
POWER & FILTERING
SAMD51G
LEDS
USB CONNECTION
MOLEX 47346-1001
BUTTON
DESIGNER
SAMD5x Datasheet: Section 56.4
2MB FLASH
SAMD5x Datasheet: Section 56.3 AREF
SAMD5x Datasheet: Section 56.2 Power
SAMD5x Datasheet: Section 56.7 Programming

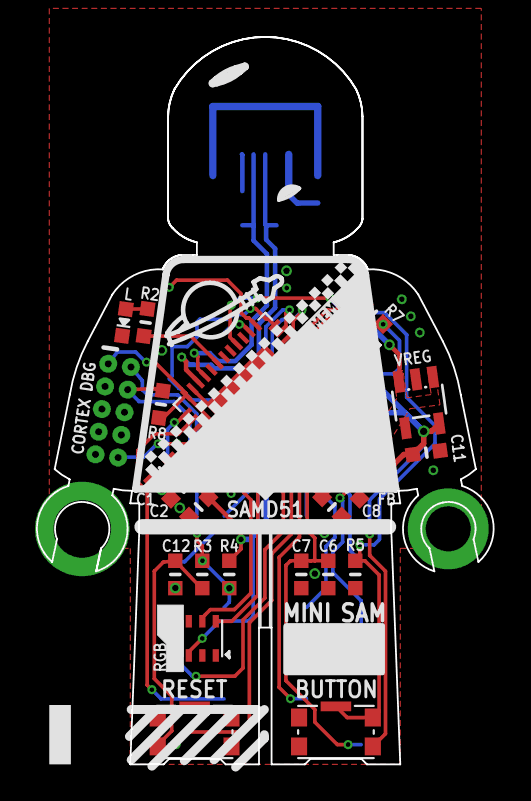
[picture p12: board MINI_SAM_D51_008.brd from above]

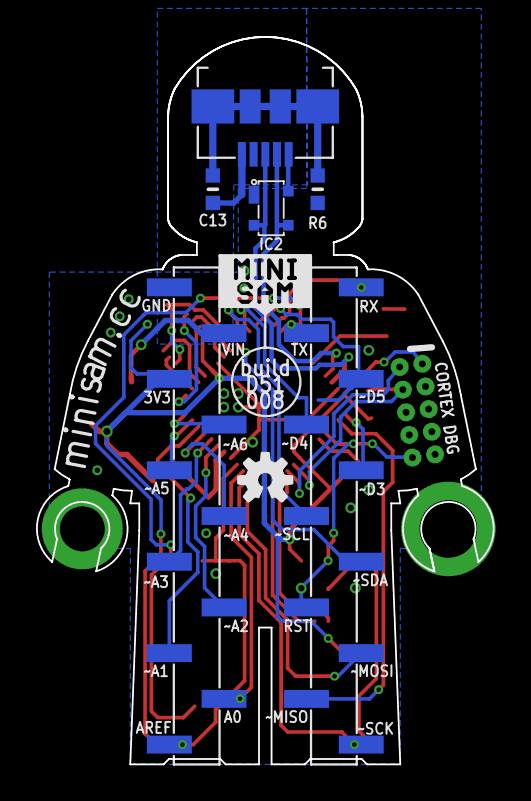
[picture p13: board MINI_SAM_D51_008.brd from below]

Board: 2 copper layers, 25.4 x 40.4 mm, 32 parts (7 on the bottom side), 41 nets.

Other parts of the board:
U$3: OSHW-LOGO-S

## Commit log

2018-07-25 Initial Commit
    Adding inital files to the repository.
    [MINI_SAM_D51_001.brd, MINI_SAM_D51_001.sch, MINI_SAM_D51_002.brd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]
2018-07-26 Updated to 006
    Mostly cosmetic updates, some associated component re-arranging.
    [MINI_SAM_D51_006.brd, MINI_SAM_D51_006.sch]
2018-07-26 More minor cosmetic changes
    Minor updates to board design and cosmetic changes.
    [MINI_SAM_D51_006.brd, MINI_SAM_D51_006.sch]
2018-07-31 Created Version 007
    Changed USB routes to match each other in length. Increased size of space logo - rearranged a couple vias in the process.
    [MINI_SAM_D51_007.brd, MINI_SAM_D51_007.sch]
2018-07-31 Removed Face tCream
    Removed the eyes and mouth tCream items that were inadvertantly added.
    [MINI_SAM_D51_007.brd]
2018-07-31 Created SAMD51-007 BOM
    Text output from EAGLE - Needs cleaning but a good start.
2018-07-31 Added v 007 Schematic
2018-07-31 Updated -007 BOM
    Cleaned up and added some clarity.
2018-08-08 Added Rev 008
    [MINI_SAM_D51_008.brd, MINI_SAM_D51_008.sch]
2018-08-08 Slight Update to Rev 007
    [MINI_SAM_D51_007.brd]
2018-08-10 Adjust VREG
    Tried a new layout with VREG aligned to torso.
    [MINI_SAM_D51_008.brd]
2018-08-14 Name Changes
    [MINI_SAM_D51_007.brd, MINI_SAM_D51_007.sch]
2018-08-14 Minor Mods
    Modified layout slightly. Will require a new sold paste template.
    [MINI_SAM_D51_008.brd]
2018-08-20 Added details for 2MB Flash
    I can't find too many USON-8 2x3mm flash devices, so I'm open to adding more options to the list.
2018-10-02 Adding revisions
    [MINI_SAM_D51_009.brd, MINI_SAM_D51_009.sch, MINI_SAM_D51_010.brd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]
2018-10-02 Update and rename SAMD51-007 to SAMD51-007.md
    BOM error message
2018-10-02 Updated VDDCORE Cap
    Updated VDDCORE cap to 4.7uF.
    [MINI_SAM_D51_016.brd, MINI_SAM_D51_016.sch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]
2018-10-03 BOM Cleanup
    Cleanup of Rev 016 BOM.
    [MINI_SAM_D51_016.brd, MINI_SAM_D51_016.sch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]
2018-12-07 Updated Board Designs
    Added new design revisions
    [MINI_SAM_D51_017.brd, MINI_SAM_D51_017.sch, MINI_SAM_D51_018.brd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]
2018-12-07 Create Mini_SAM_D51_r017
    BOM for R017 version boards. These boards use a PLCC-2 reverse gullwing led on the back.
2018-12-07 File Relocations
    Moving files to combine M0 and M4 Mini SAM variants.
    [MINI_SAM_D51_001.brd, MINI_SAM_D51_001.sch, MINI_SAM_D51_002.brd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]
2018-12-07 Adding new Mini SAM M0
    [MINI_SAM_D21_r001_b001.brd, MINI_SAM_D21_r001_b001.sch]
2019-05-15 Added Board
    [MINI_SAM_D51_r020_b002_Seeed.brd, MINI_SAM_D51_r020_b002_Seeed.sch]
2019-09-11 Added Rev 025
    [MINI_SAM_D51_r025_b001.brd, MINI_SAM_D51_r025_b001.sch]
2020-01-02 Add AfterDark Source Files
    Added the PCB source files for the Afterdark version. This removes ground fills and adds a hole for backlit LED. Use this file with OSHPARK Afterdark service.
    [MINI_SAM_D51_rAD1_b002.brd, MINI_SAM_D51_rAD1_b002.sch]

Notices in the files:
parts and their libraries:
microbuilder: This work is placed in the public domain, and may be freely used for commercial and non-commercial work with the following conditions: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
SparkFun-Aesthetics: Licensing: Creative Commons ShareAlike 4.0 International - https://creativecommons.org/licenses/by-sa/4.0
